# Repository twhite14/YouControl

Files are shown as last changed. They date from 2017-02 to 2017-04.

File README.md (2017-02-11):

# YouControl
An open source game controller for PC

##Requirements:
Arduino 1.8.1
Teensyduino 1.35
Teensy LC Microcontroller

##Getting started:
Install the Arduino IDE, then navigate to its path (either where you extracted it or C:\Program Files (x86)\Arduino\)
Navigate to hardware\teensy\avr\ and replace the boards.txt with the one in this repo's avr directory.
Navigate to hardware\teensy\avr\cores\teensy3\ and replace the files in that directory with those in this repo's teensy3 directory.
Test that the Buttons Arduino project compiles properly using both the standard Keyboard + Mouse + Joystick option and the YouControl copy.

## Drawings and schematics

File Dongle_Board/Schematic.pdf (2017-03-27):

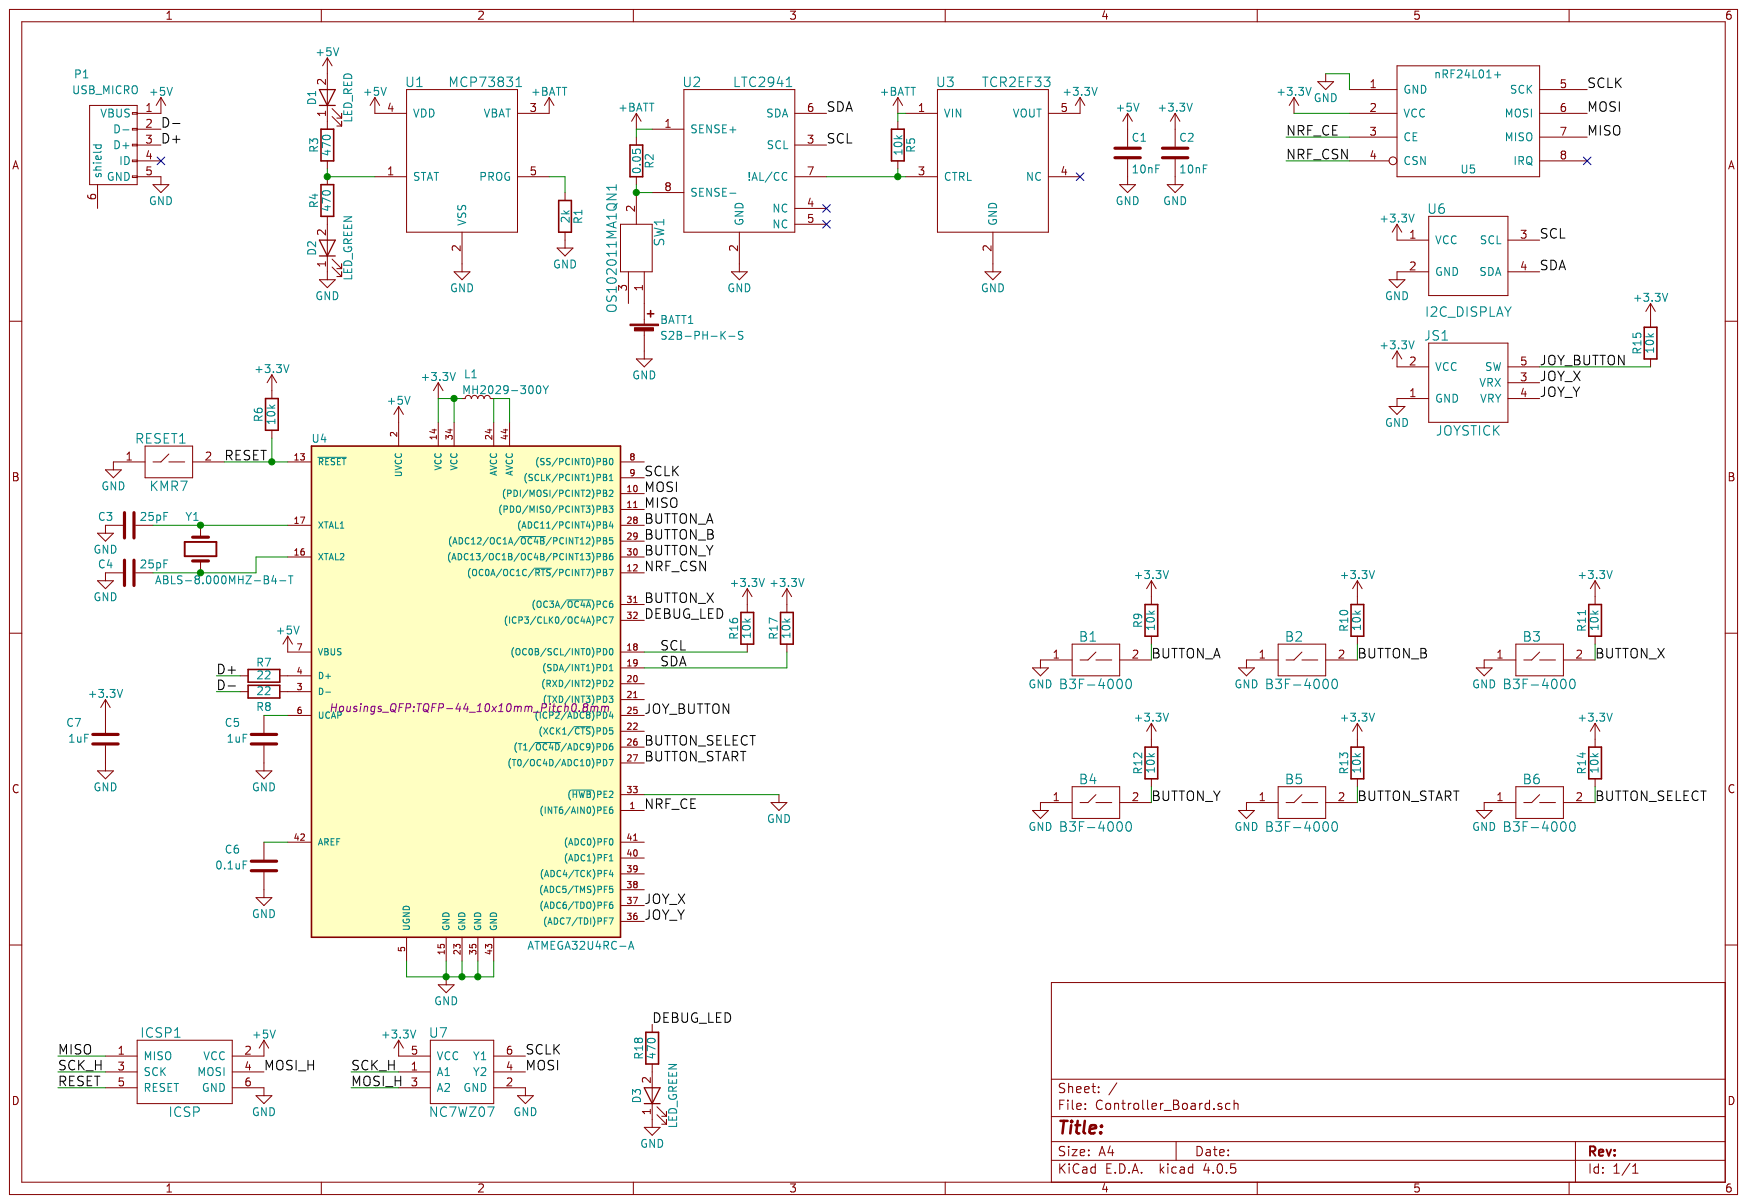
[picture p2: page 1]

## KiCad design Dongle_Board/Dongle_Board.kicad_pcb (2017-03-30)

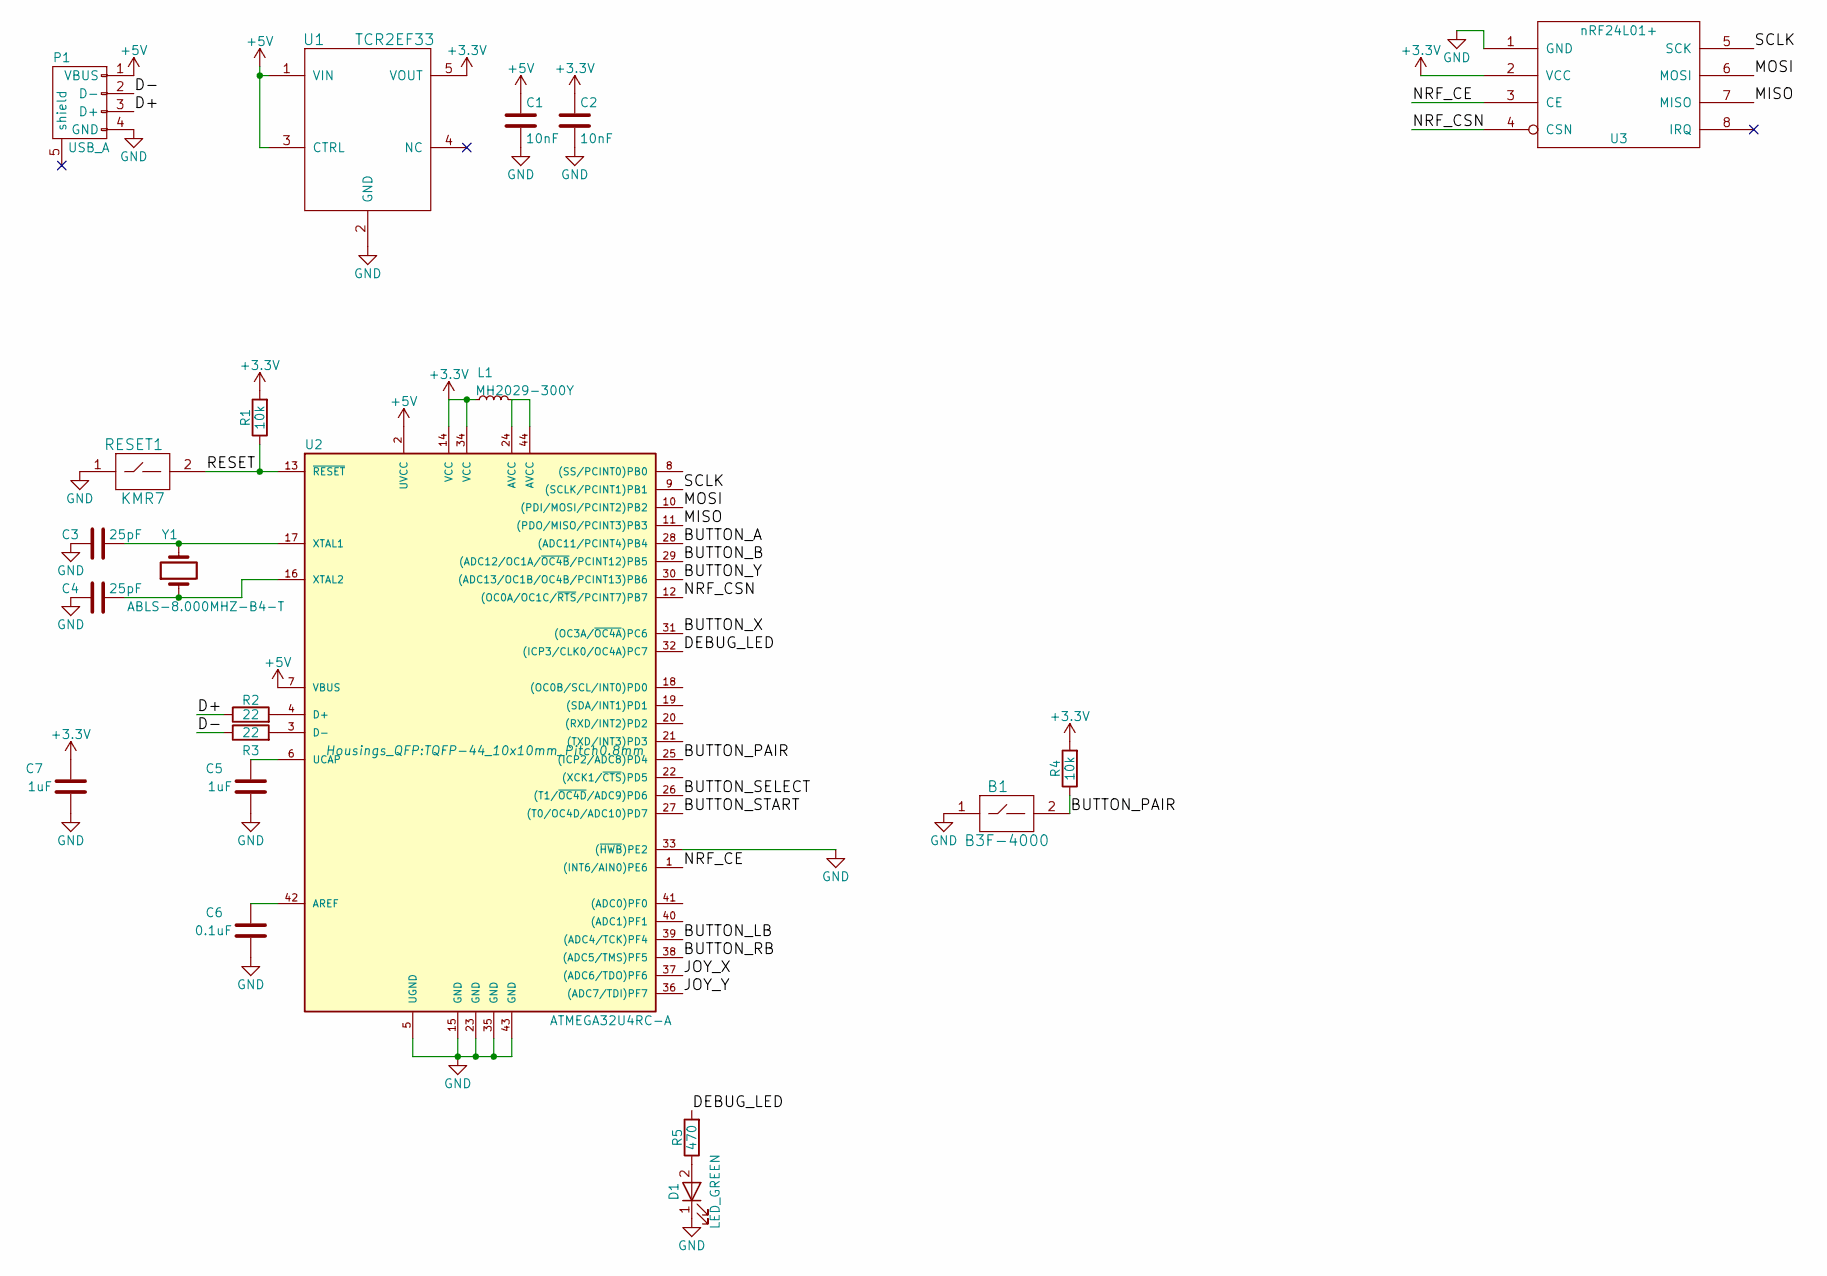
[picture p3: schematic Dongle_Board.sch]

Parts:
B1: B3F-4000; Button_Dual
C1, C2: 10nF; C_0603_HandSoldering
C3, C4: 25pF; C_0603_HandSoldering
C5, C7: 1uF; C_0603_HandSoldering
C6: 0.1uF; C_0603_HandSoldering
D1: LED_GREEN; D_0603
L1: MH2029-300Y; R_0805_HandSoldering
P1: USB_A; USB_A_No_Border
R1, R4: 10k; R_0603_HandSoldering
R2, R3: 22; R_0603_HandSoldering
R5: 470; R_0603_HandSoldering
RESET1: KMR7; SW_SPST_KMR2
U1: TCR2EF33; TSOT-23-5_HandSoldering
U2: ATMEGA32U4RC-A; TQFP-44_10x10mm_Pitch0.8mm
U3: nRF24L01+; nRF24L01_Breakout
Y1: ABLS-8.000MHZ-B4-T; Crystal_SMD_HC49-SD

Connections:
+3V3: C2.1, C7.2, L1.1, R1.2, R4.2, U1.5 (VOUT), U2.14 (VCC), U2.34 (VCC), U3.2 (VCC)
+5V: C1.1, P1.1 (VBUS), U1.1 (VIN), U1.3 (CTRL), U2.2 (UVCC), U2.7 (VBUS)
/BUTTON_A: U2.28 ((ADC11/PCINT4)PB4)
/BUTTON_B: U2.29 ((ADC12/OC1A/~OC4B~/PCINT12)PB5)
/BUTTON_LB: U2.39 ((ADC4/TCK)PF4)
/BUTTON_PAIR: B1.2, R4.1, U2.25 ((ICP2/ADC8)PD4)
/BUTTON_RB: U2.38 ((ADC5/TMS)PF5)
/BUTTON_SELECT: U2.26 ((T1/~OC4D~/ADC9)PD6)
/BUTTON_START: U2.27 ((T0/OC4D/ADC10)PD7)
/BUTTON_X: U2.31 ((OC3A/~OC4A~)PC6)
/BUTTON_Y: U2.30 ((ADC13/OC1B/OC4B/PCINT13)PB6)
/D+: P1.3 (D+), R2.1
/D-: P1.2 (D-), R3.1
/DEBUG_LED: R5.2, U2.32 ((ICP3/CLK0/OC4A)PC7)
/JOY_X: U2.37 ((ADC6/TDO)PF6)
/JOY_Y: U2.36 ((ADC7/TDI)PF7)
/MISO: U2.11 ((PDO/MISO/PCINT3)PB3), U3.7 (MISO)
/MOSI: U2.10 ((PDI/MOSI/PCINT2)PB2), U3.6 (MOSI)
/NRF_CE: U2.1 ((INT6/AIN0)PE6), U3.3 (CE)
/NRF_CSN: U2.12 ((OC0A/OC1C/~RTS~/PCINT7)PB7), U3.4 (CSN)
/RESET: R1.1, RESET1.2, U2.13 (~RESET~)
/SCLK: U2.9 ((SCLK/PCINT1)PB1), U3.5 (SCK)
GND: B1.1, C1.2, C2.2, C3.1, C4.1, C5.1, C6.1, C7.1, D1.1 (K), P1.4 (GND), RESET1.1, U1.2 (GND), U2.5 (UGND), U2.15 (GND), U2.23 (GND), U2.33 ((~HWB~)PE2), U2.35 (GND), U2.43 (GND), U3.1 (GND)
unnamed: C3.2, U2.17 (XTAL1), Y1.2
unnamed: C4.2, U2.16 (XTAL2), Y1.1
unnamed: C5.2, U2.6 (UCAP)
unnamed: C6.2, U2.42 (AREF)
unnamed: D1.2 (A), R5.1
unnamed: L1.2, U2.24 (AVCC), U2.44 (AVCC)
unnamed: R2.2, U2.4 (D+)
unnamed: R3.2, U2.3 (D-)

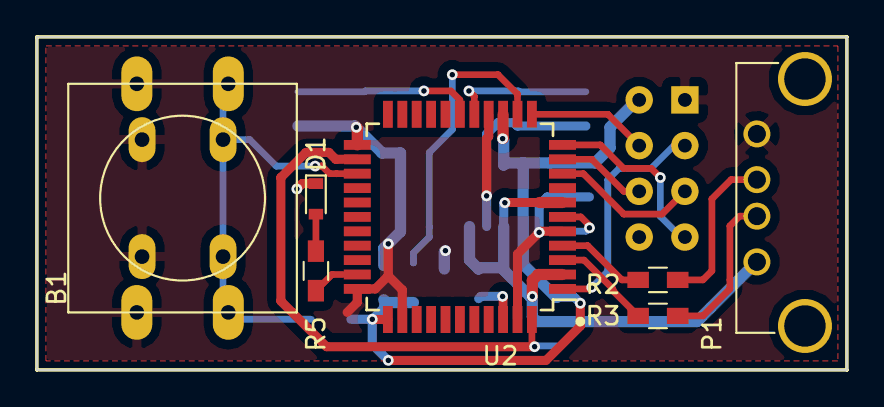
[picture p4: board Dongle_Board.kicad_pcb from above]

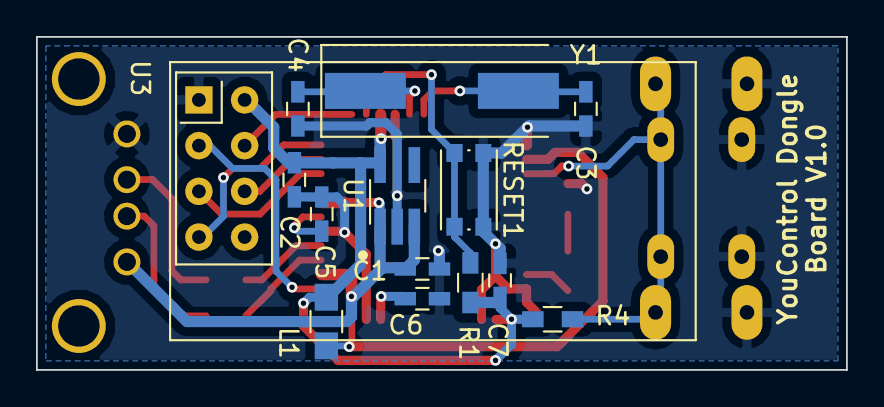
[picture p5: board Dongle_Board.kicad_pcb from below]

Board: 2 copper layers, 45.0 x 18.5 mm, 21 parts (14 on the bottom side), 21 nets.

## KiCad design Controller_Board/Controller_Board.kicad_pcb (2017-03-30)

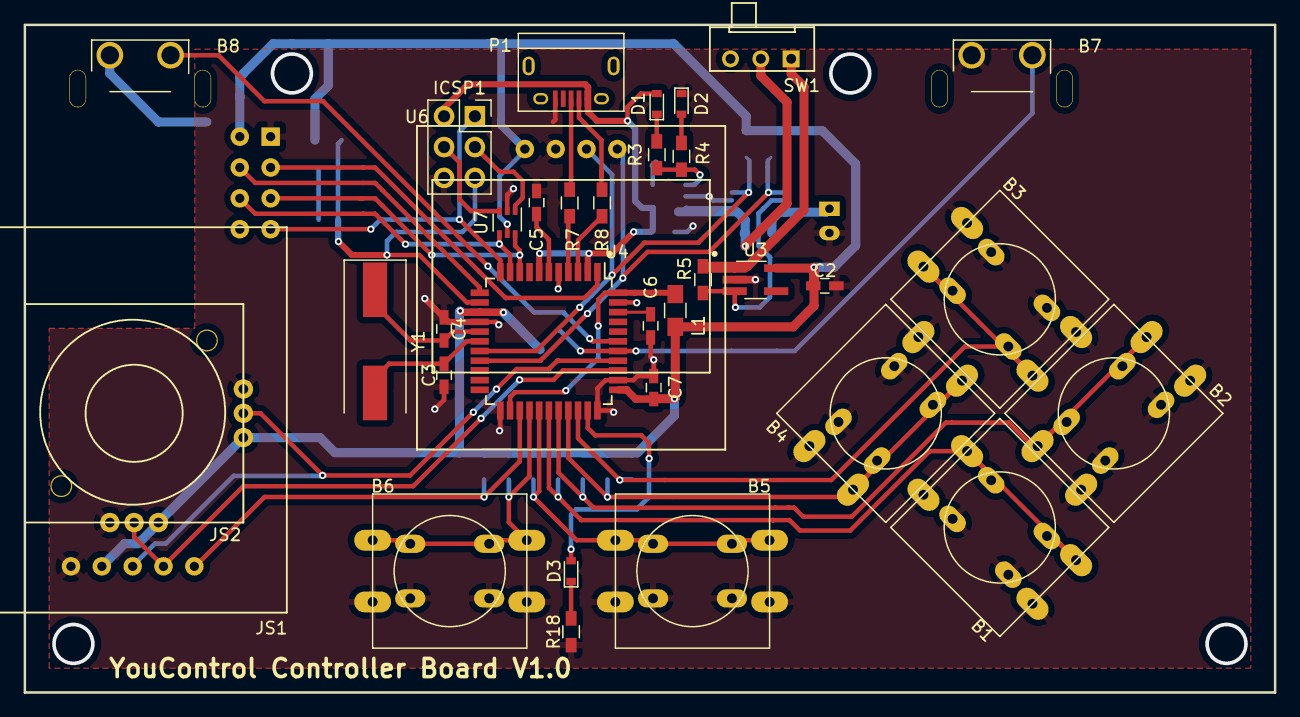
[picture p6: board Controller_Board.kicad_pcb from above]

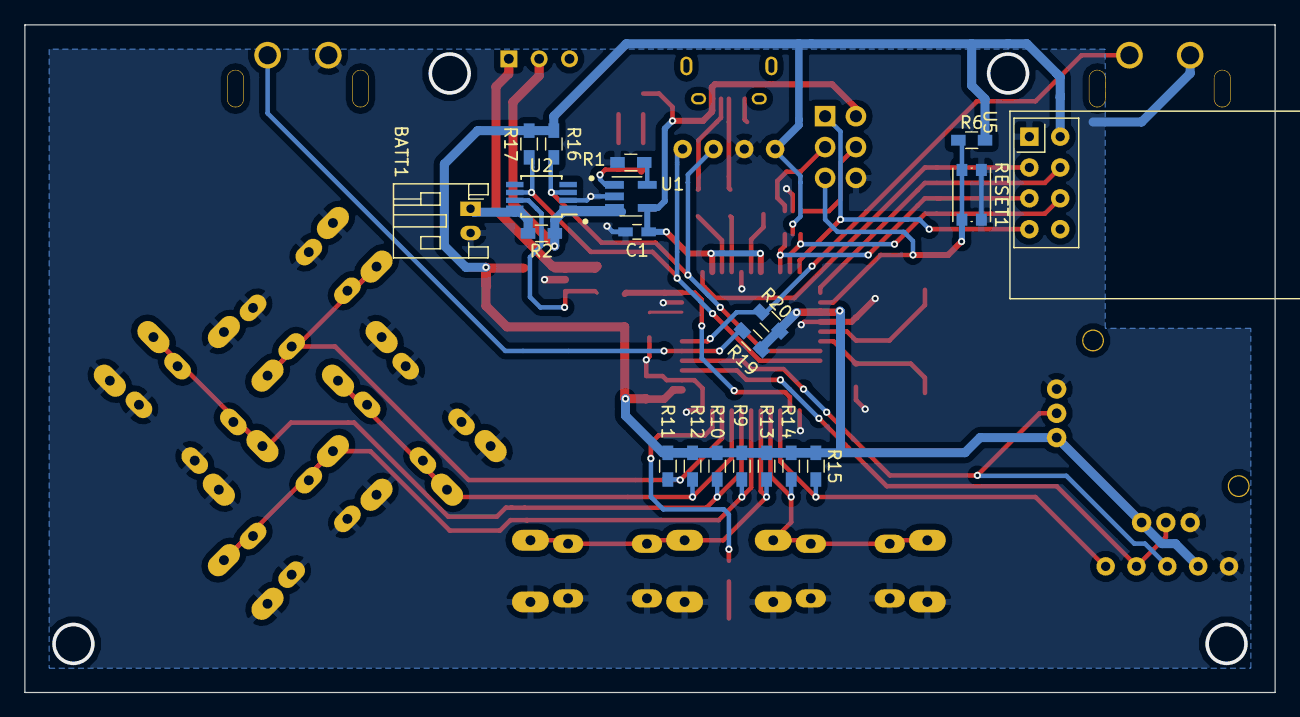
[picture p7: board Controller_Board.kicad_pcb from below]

Board: 2 copper layers, 103.0 x 55.0 mm, 54 parts (20 on the bottom side), 43 nets.

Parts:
B1, B2, B3, B4, B5, B6: B3F-4000; Button_Dual
B7, B8: B3F-4000; Button_Right_Angle
BATT1: S2B-PH-K-S; JST_PH_S2B-PH-K_02x2.00mm_Angled
C1, C2: 10nF; C_0603_HandSoldering
C3, C4: 25pF; C_0603_HandSoldering
C5, C7: 1uF; C_0603_HandSoldering
C6: 0.1uF; C_0603_HandSoldering
D1: LED_RED; D_0603
D2, D3: LED_GREEN; D_0603
ICSP1: ICSP; Socket_Strip_Straight_2x03_Pitch2.54mm
JS1: JOYSTICK; Joystick_PlayStation
JS2: JOYSTICK_Adafruit; Joystick_Adafruit
L1: MH2029-300Y; R_0805_HandSoldering
P1: USB_MICRO; USB_Micro-B
R1: 2k; R_0603_HandSoldering
R2: 0.05; R_0603_HandSoldering
R3, R4, R18: 470; R_0603_HandSoldering
R5, R6, R9, R10, R11, R12, R13, R14, R15, R16, R17, R19, R20: 10k; R_0603_HandSoldering
R7, R8: 22; R_0603_HandSoldering
RESET1: KMR7; SW_SPST_KMR2
SW1: OS102011MA1QN1; MHSS1105
U1: MCP73831; SOT-23-5_HandSoldering
U2: LTC2941; MSOP-8_3x3mm_Pitch0.65mm
U3: TCR2EF33; TSOT-23-5_HandSoldering
U4: ATMEGA32U4RC-A; TQFP-44_10x10mm_Pitch0.8mm
U5: nRF24L01+; nRF24L01_Breakout
U6: I2C_DISPLAY; I2C_Screen
U7: NC7WZ07; SOT-363_SC-70-6
Y1: ABLS-8.000MHZ-B4-T; Crystal_SMD_HC49-SD

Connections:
+3V3: C2.1, C7.2, JS1.2, JS2.3, JS2.4, L1.1, R6.2, R9.2, R10.2, R11.2, R12.2, R13.2, R14.2, R15.2, R16.2, R17.2, R19.2, R20.2, U3.5, U4.14, U4.34, U5.2, U6.1, U7.5
+5V: C1.1, D1.2, ICSP1.2, P1.1, U1.4, U4.2, U4.7
+BATT: R2.1, SW1.2, U1.3, U2.1
/BUTTON_A: B1.2, R9.1, U4.28
/BUTTON_B: B2.2, R10.1, U4.29
/BUTTON_LB: B8.2, R20.1, U4.39
/BUTTON_RB: B7.2, R19.1, U4.38
/BUTTON_SELECT: B6.2, R14.1, U4.26
/BUTTON_START: B5.2, R13.1, U4.27
/BUTTON_X: B3.2, R11.1, U4.31
/BUTTON_Y: B4.2, R12.1, U4.30
/D+: P1.3, R7.1
/D-: P1.2, R8.1
/DEBUG_LED: D3.2, U4.32
/JOY_BUTTON: JS1.5, R15.1, U4.25
/JOY_X: JS1.3, JS2.5, U4.37
/JOY_Y: JS1.4, JS2.2, U4.36
/MISO: ICSP1.1, U4.11, U5.7
/MOSI: U4.10, U5.6, U7.4
/MOSI_H: ICSP1.4, U7.3
/NRF_CE: U4.1, U5.3
/NRF_CSN: U4.12, U5.4
/RESET: ICSP1.5, R6.1, RESET1.2, U4.13
/SCK_H: ICSP1.3, U7.1
/SCL: R16.1, U2.3, U4.18, U6.3
/SCLK: U4.9, U5.5, U7.6
/SDA: R17.1, U2.6, U4.19, U6.4
GND: B1.1, B2.1, B3.1, B4.1, B5.1, B6.1, B7.1, B8.1, BATT1.2, C1.2, C2.2, C3.1, C4.1, C5.1, C6.1, C7.1, D2.1, ICSP1.6, JS1.1, JS2.1, JS2.6, P1.5, R1.2, R18.1, RESET1.1, U1.2, U2.2, U3.2, U4.5, U4.15, U4.23, U4.33, U4.35, U4.43, U5.1, U6.2, U7.2
unnamed: BATT1.1, R2.2, U2.8
unnamed: C3.2, U4.17, Y1.2
unnamed: C4.2, U4.16, Y1.1
unnamed: C5.2, U4.6
unnamed: C6.2, U4.42
unnamed: D1.1, R3.2
unnamed: D2.2, R4.1
unnamed: D3.1, R18.2
unnamed: L1.2, U4.24, U4.44
unnamed: R1.1, U1.5
unnamed: R3.1, R4.2, U1.1
unnamed: R5.1, SW1.1, U3.1
unnamed: R5.2, U2.7, U3.3
unnamed: R7.2, U4.4
unnamed: R8.2, U4.3

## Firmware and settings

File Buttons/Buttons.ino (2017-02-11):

/* Buttons to USB Keyboard Example

   You must select Keyboard from the "Tools > USB Type" menu

   This example code is in the public domain.
*/

#include <Bounce.h>

// Create Bounce objects for each button.  The Bounce object
// automatically deals with contact chatter or "bounce", and
// it makes detecting changes very simple.
Bounce button0 = Bounce(0, 10);
Bounce button1 = Bounce(1, 10);  // 10 = 10 ms debounce time
Bounce button2 = Bounce(2, 10);  // which is appropriate for
Bounce button3 = Bounce(3, 10);  // most mechanical pushbuttons
Bounce button4 = Bounce(4, 10);
Bounce button5 = Bounce(5, 10);  // if a button is too "sensitive"
Bounce button6 = Bounce(6, 10);  // to rapid touch, you can
Bounce button7 = Bounce(7, 10);  // increase this time.
Bounce button8 = Bounce(8, 10);
Bounce button9 = Bounce(9, 10);

void setup() {
  // Configure the pins for input mode with pullup resistors.
  // The pushbuttons connect from each pin to ground.  When
  // the button is pressed, the pin reads LOW because the button
  // shorts it to ground.  When released, the pin reads HIGH
  // because the pullup resistor connects to +5 volts inside
  // the chip.  LOW for "on", and HIGH for "off" may seem
  // backwards, but using the on-chip pullup resistors is very
  // convenient.  The scheme is called "active low", and it's
  // very commonly used in electronics... so much that the chip
  // has built-in pullup resistors!
  pinMode(0, INPUT_PULLUP);
  pinMode(1, INPUT_PULLUP);
  pinMode(2, INPUT_PULLUP);
  pinMode(3, INPUT_PULLUP);
  pinMode(4, INPUT_PULLUP);
  pinMode(5, INPUT_PULLUP);
  pinMode(6, INPUT_PULLUP);  // Teensy++ LED, may need 1k resistor pullup
  pinMode(7, INPUT_PULLUP);
  pinMode(8, INPUT_PULLUP);
  pinMode(9, INPUT_PULLUP);
}

void loop() {
  // Update all the buttons.  There should not be any long
  // delays in loop(), so this runs repetitively at a rate
  // faster than the buttons could be pressed and released.
  button0.update();
  button1.update();
  button2.update();
  button3.update();
  button4.update();
  button5.update();
  button6.update();
  button7.update();
  button8.update();
  button9.update();

  // Check each button for "falling" edge.
  // Type a message on the Keyboard when each button presses
  // Update the Joystick buttons only upon changes.
  // falling = high (not pressed - voltage from pullup resistor)
  //           to low (pressed - button connects pin to ground)
  if (button0.fallingEdge()) {
    Keyboard.println("B0 press");
  }
  if (button1.fallingEdge()) {
    Keyboard.println("B1 press");
  }
  if (button2.fallingEdge()) {
    Keyboard.println("B2 press");
  }
  if (button3.fallingEdge()) {
    Keyboard.println("B3 press");
  }
  if (button4.fallingEdge()) {
    Keyboard.println("B4 press");
  }
  if (button5.fallingEdge()) {
    Keyboard.println("B5 press");
  }
  if (button6.fallingEdge()) {
    Keyboard.println("B6 press");
  }
  if (button7.fallingEdge()) {
    Keyboard.println("B7 press");
  }
  if (button8.fallingEdge()) {
    Keyboard.println("B8 press");
  }
  if (button9.fallingEdge()) {
    Keyboard.println("B9 press");
  }

  // Check each button for "rising" edge
  // Type a message on the Keyboard when each button releases.
  // For many types of projects, you only care when the button
  // is pressed and the release isn't needed.
  // rising = low (pressed - button connects pin to ground)
  //          to high (not pressed - voltage from pullup resistor)
  if (button0.risingEdge()) {
    Keyboard.println("B0 release");
  }
  if (button1.risingEdge()) {
    Keyboard.println("B1 release");
  }
  if (button2.risingEdge()) {
    Keyboard.println("B2 release");
  }
  if (button3.risingEdge()) {
    Keyboard.println("B3 release");
  }
  if (button4.risingEdge()) {
    Keyboard.println("B4 release");
  }
  if (button5.risingEdge()) {
    Keyboard.println("B5 release");
  }
  if (button6.risingEdge()) {
    Keyboard.println("B6 release");
  }
  if (button7.risingEdge()) {
    Keyboard.println("B7 release");
  }
  if (button8.risingEdge()) {
    Keyboard.println("B8 release");
  }
  if (button9.risingEdge()) {
    Keyboard.println("B9 release");
  }
}

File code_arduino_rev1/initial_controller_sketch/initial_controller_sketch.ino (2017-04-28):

#include <SPI.h>
#include <Wire.h>
#include "RF24.h"
#include <Adafruit_GFX.h>
#include <Adafruit_SSD1306.h>

/*DEFINE SETUPS*/
#define OLED_RESET 4
Adafruit_SSD1306 display(OLED_RESET);

/*PIN SETUPS*/
int ButtonA = 8;
int ButtonB = 9;
int ButtonX = 5;
int ButtonY = 10;
int ButtonStart = 6;//gotta define these after final implementation
int ButtonSelect = 12;
int ButtonRbump = A2;
int ButtonLbump = A3;
int Xaxis = A1;
int Yaxis = A0;
int count = 0;
bool cntrl_assign = false;
RF24 radio(7,11);
byte addresses[][6] = {"1Node","2Node"}; //first is check pipe second is feedback
long pipeassign;
long getassign;
/*setup======================================================*/
void setup() {
//start lcd
Serial.begin(115200);
  display.begin(SSD1306_SWITCHCAPVCC, 0x3C);
  display.display();
  delay(4000);
  display.clearDisplay();
//start radio
  radio.begin();//start it
  radio.setDataRate(RF24_2MBPS);
  radio.setPALevel(RF24_PA_MAX);
  radio.openWritingPipe(addresses[1]);
  radio.openReadingPipe(1,addresses[0]);//open check pipe
  radio.startListening();//start listening on the pipe
//button setup
  pinMode(ButtonA,INPUT);
  pinMode(ButtonB,INPUT);
  pinMode(ButtonY,INPUT);
  pinMode(ButtonX,INPUT);
}
/*loop=======================================================*/
long selector = 1;
void loop() {
    display.clearDisplay();
    display.setTextSize(1);
    display.setTextColor(WHITE);
  while(!cntrl_assign){//while not assigned, check for assignment value
      delay(100);
      display.clearDisplay();
      display.setTextSize(1);
      display.setTextColor(WHITE);
      display.setCursor(0,16);
      display.println("start to change #,");
      display.setCursor(0,26);
      display.println("select to confirm :");
      
        //cntrl_assign = true;
      
      if(digitalRead(ButtonStart) == LOW){
        selector++;
        if (selector == 5){selector = 1;}
      }
      if (selector == 1){
        display.setCursor(0,0);
        display.println("[Controller 1]");
      }
      else if (selector == 2){
        display.setCursor(0,0);
        display.println("[Controller 2]");
      }
      else if (selector == 3){
        display.setCursor(0,0);
        display.println("[Controller 3]");
      }
      else if (selector == 4){
        display.setCursor(0,0);
        display.println("[Controller 4]");
      }
      display.display();
      if(digitalRead(ButtonSelect) == LOW){
         cntrl_assign = true;
      }
    }
  long dispnum = selector - 1;
  radio.stopListening();
  radio.openWritingPipe(addresses[1]);
  
  while(cntrl_assign){
    unsigned long sendmsg = statusreturn(dispnum);
    radio.write(&sendmsg,sizeof(unsigned long));
    delay(10);
    if(count>=20){
  //    update screen stuff
  //    check battery levels
    
      display.clearDisplay();
      display.setTextSize(1);
      display.setTextColor(WHITE);
      display.setCursor(0,30);
      display.println("ctrl #");
      display.setTextSize(2);
      display.setCursor(20,40);
      display.print(selector,DEC);
      display.display();
      count = 0;
    }
    count++;
  }
  
}
/*statusreturn===============================================*/
long statusreturn(long cntrlnum){ //status of all states
  long stat = 0;
  long a     = digitalRead(ButtonA);
  long b     = digitalRead(ButtonB);
  long x     = digitalRead(ButtonX);
  long y     = digitalRead(ButtonY);
  long sta   = digitalRead(ButtonStart);
  long sel   = digitalRead(ButtonSelect);
  long rbump = digitalRead(ButtonRbump);
  long lbump = digitalRead(ButtonLbump);
  long xax   = analogRead(Xaxis)/4;
  long yax   = analogRead(Yaxis)/4;

  //OR the bitshifted states to make 4 byte state
  //DIO 0-7B 
  //Analog 8-15B, 16-23B
  //controller number 24-31B
  stat |= (a); 
  stat |= (b << 1);
  stat |= (x << 2);
  stat |= (y << 3);
  stat |= (sta << 4); 
  stat |= (sel << 5);
  stat |= (rbump << 6);
  stat |= (lbump << 7);
  stat |= (xax << 8);
  stat |= (yax << 16);
  stat |= (cntrlnum << 24);
  Serial.println(stat,HEX);
  
  return stat;
}//end statusreturn

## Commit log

2017-02-10 Added joystick test program for Arduino Micro. Emulates 4 joysticks.
2017-02-11 Original Teensy files. Multijoystick functions to be added here
2017-02-11 Moved boards.txt to a more logical directory. Updated a few typos (previously overwrote other interface)
2017-02-11 Added Buttons test file to test my copy of keyboard/mouse/joystick. Works.
2017-02-14 Found a basic joystick tester compatible with Teensy
2017-02-14 Updated joystick test programs for Micro and Teensy.
2017-02-16 Fixed a typo in array offsets
    [MultipleJoystickTest2.ino]
2017-03-05 Created controller board schematic in KiCad
    [Controller_Board.kicad_pcb, Controller_Board.sch]
2017-03-05 Placed almost all connections, power connections to follow
    [Controller_Board.sch]
2017-03-27 Updated Controller Board with shoulder buttons, mounting holes, slightly altered pinout, second analog stick option, dual button footprints.... I really should have done this in stages...
    [Controller_Board - Copy.kicad_pcb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]
2017-03-27 Created Dongle Board, a copy of the Controller Board minus the extra buttons and with a USB A connector instead of a micro USB. Also realize now that a controller could just as well act as a dongle i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
    [Controller_Board-B.Cu.gbr, Controller_Board-B.Mask.gbr, Controller_Board-B.SilkS.gbr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]
2017-03-30 Updated Dongle and Controller boards, ready for fab
    [Controller_Board.kicad_pcb, Dongle_Board.kicad_pcb]
2017-04-29 Removed references to Teensy
